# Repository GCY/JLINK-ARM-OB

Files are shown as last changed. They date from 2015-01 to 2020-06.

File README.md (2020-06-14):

# JLINK-ARM-OB
This is JLink-OB ARM ICE tool, [STM32F103 Jan 7 2019 firmware](https://github.com/GCY/JLINK-ARM-OB/blob/master/J-Link%20OB-STM32F103%20V1%20compiled%20Jan%20%207%202019/JLink-OB%20STM32F103%20JLinkARM.dll%20v6.44f%20.bin) extract from v6.44 JLinkARM.dll.

This version([STM32F103 Jan 7 2019](https://github.com/GCY/JLINK-ARM-OB/blob/master/J-Link%20OB-STM32F103%20V1%20compiled%20Jan%20%207%202019/JLink-OB%20STM32F103%20JLinkARM.dll%20v6.44f%20.bin) ) failed to upgrade the firmware of the JLink-OB with JLinkConfig.

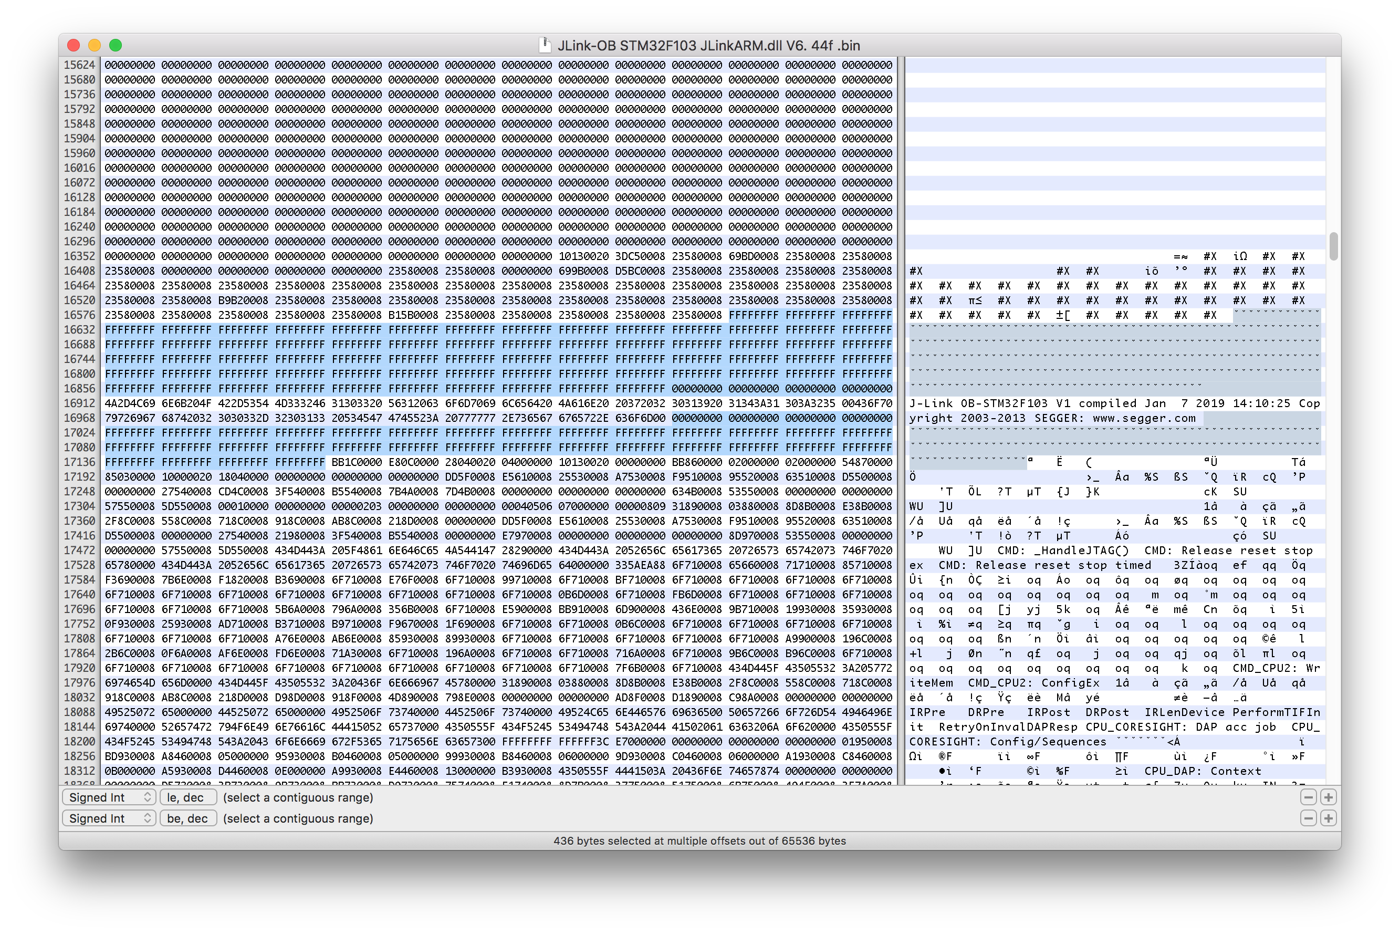
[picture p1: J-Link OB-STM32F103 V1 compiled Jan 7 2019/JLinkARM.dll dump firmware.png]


## Use
 - 1.burning [STM32F103 Jan 7 2019 firmware](https://github.com/GCY/JLINK-ARM-OB/blob/master/J-Link%20OB-STM32F103%20V1%20compiled%20Jan%20%207%202019/JLink-OB%20STM32F103%20JLinkARM.dll%20v6.44f%20.bin) to DIY JLink-OB.
 - 2.Connect targer(For example the following picture is my [STM32F405 Digital Stethoscope project](https://github.com/GCY/Digital-Stethoscope-for-Heart-and-Lung-sounds))
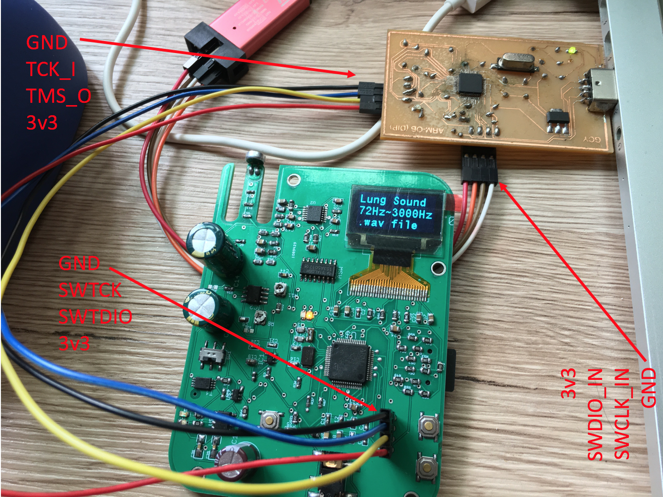
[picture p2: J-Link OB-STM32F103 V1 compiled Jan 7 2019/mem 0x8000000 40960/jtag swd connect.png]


 - 1.Run JLinkExe.
 - 2.J-Link > connect.
 - 3.Select device.     # the example is STM32F405
 - 4.Device > S.        # for SWD Port
 - 5.Speed = 4000kHz
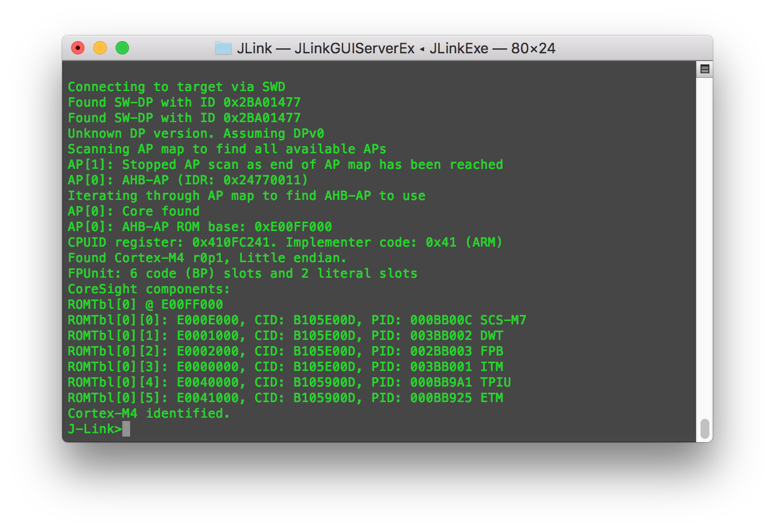
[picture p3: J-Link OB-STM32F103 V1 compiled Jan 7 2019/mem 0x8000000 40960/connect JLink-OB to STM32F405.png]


 - 1.J-Link > mem 0x8000000 40960
 - 2.Test dump target flash.
 - 3.You DIY JLink-OB done.
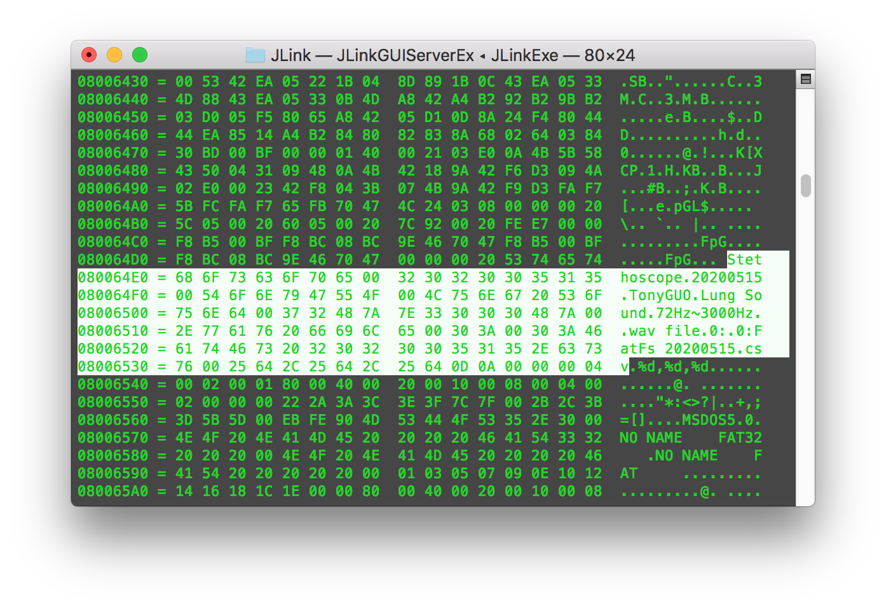
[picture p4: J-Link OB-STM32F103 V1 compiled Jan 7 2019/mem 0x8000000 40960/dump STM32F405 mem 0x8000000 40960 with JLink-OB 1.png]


## Reference
 - [DIY JLink-OB-072 (JLink + COM)](http://akb77.com/g/stm32/jlink-ob/)
 - [JLink hack reference (cht)](https://www.amobbs.com/thread-5653964-1-1.html)
 - [J-Link Commander](https://wiki.segger.com/J-Link_Commander#savebin)
 - [Firmware extract from JLinkARM.dll (cht)](https://blog.csdn.net/qq_39663845/article/details/81086499)

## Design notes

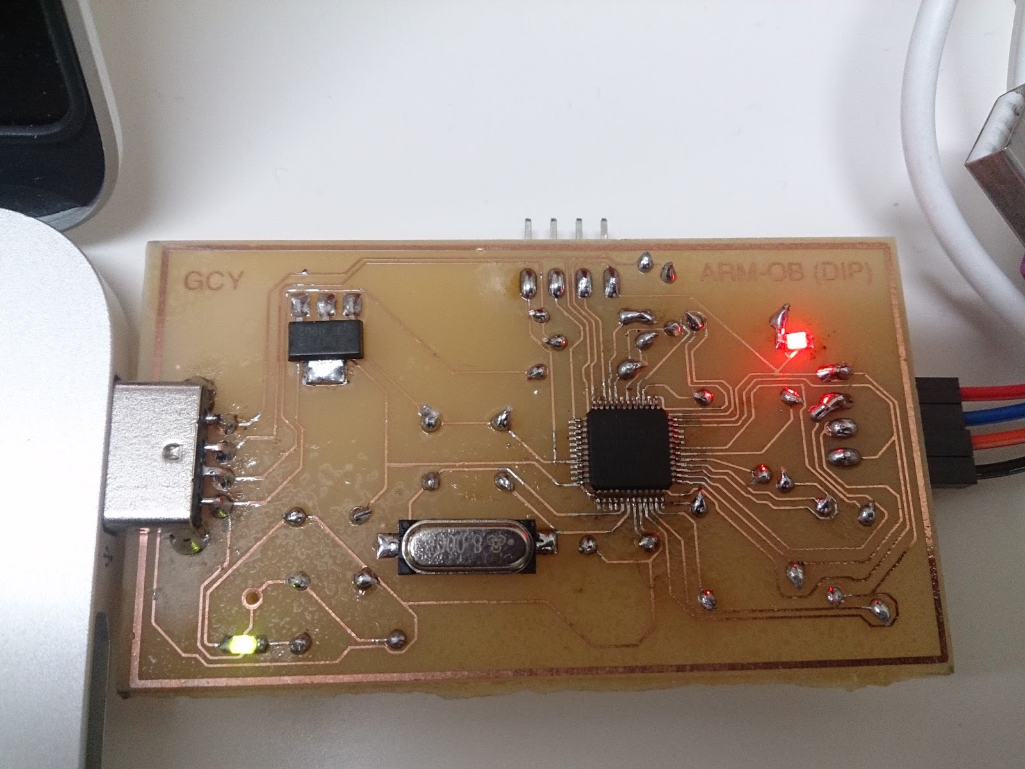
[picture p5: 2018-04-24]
2012 version/hw example.JPG

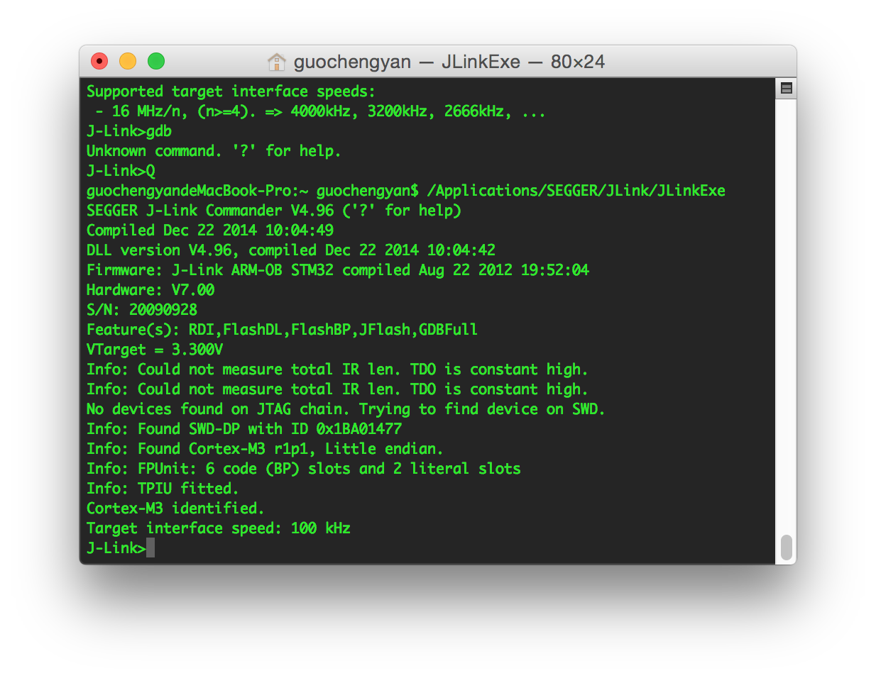
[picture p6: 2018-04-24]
2012 version/J-Link Commander.png

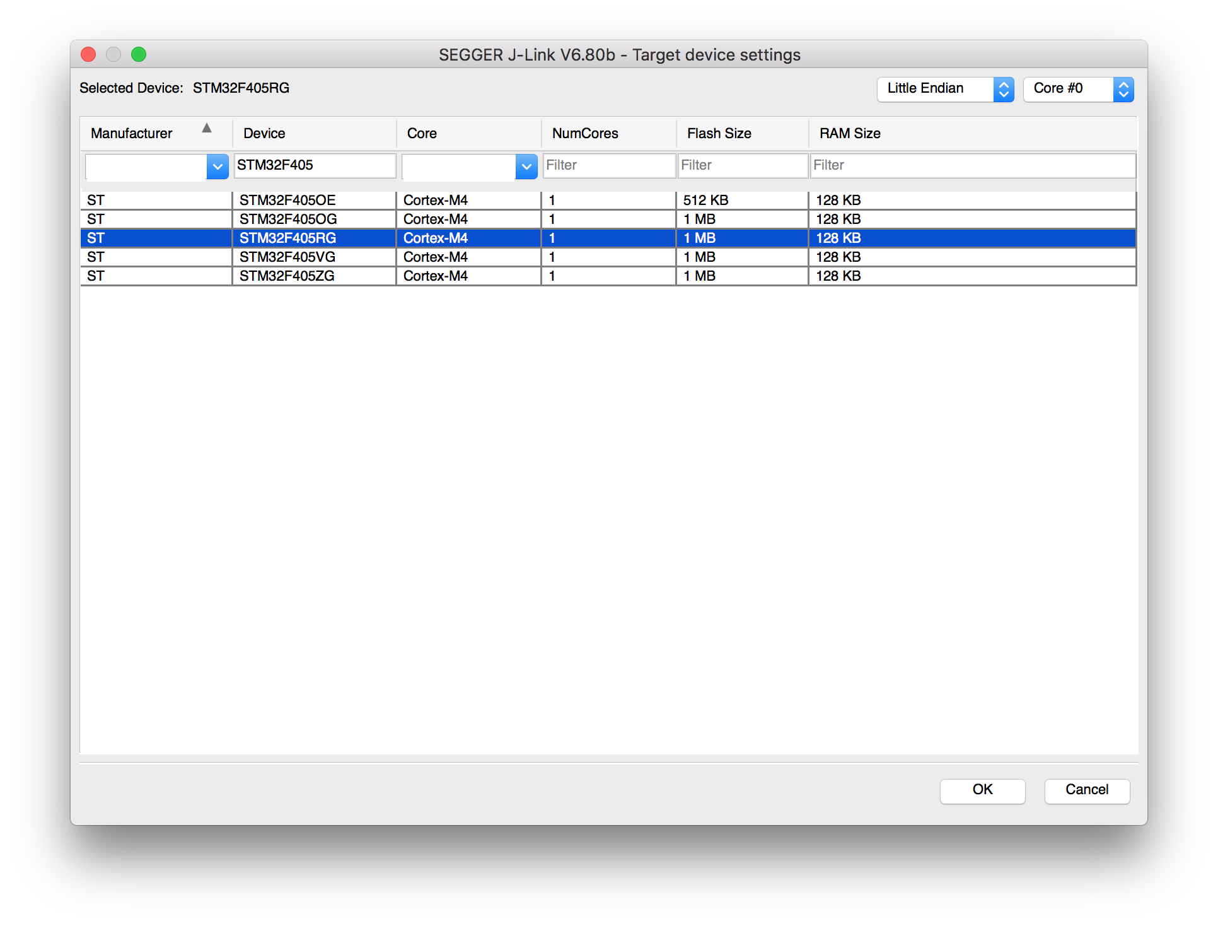
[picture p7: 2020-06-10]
J-Link OB-STM32F103 V1 compiled Jan 7 2019/mem 0x8000000 40960/STM32F405 device.png

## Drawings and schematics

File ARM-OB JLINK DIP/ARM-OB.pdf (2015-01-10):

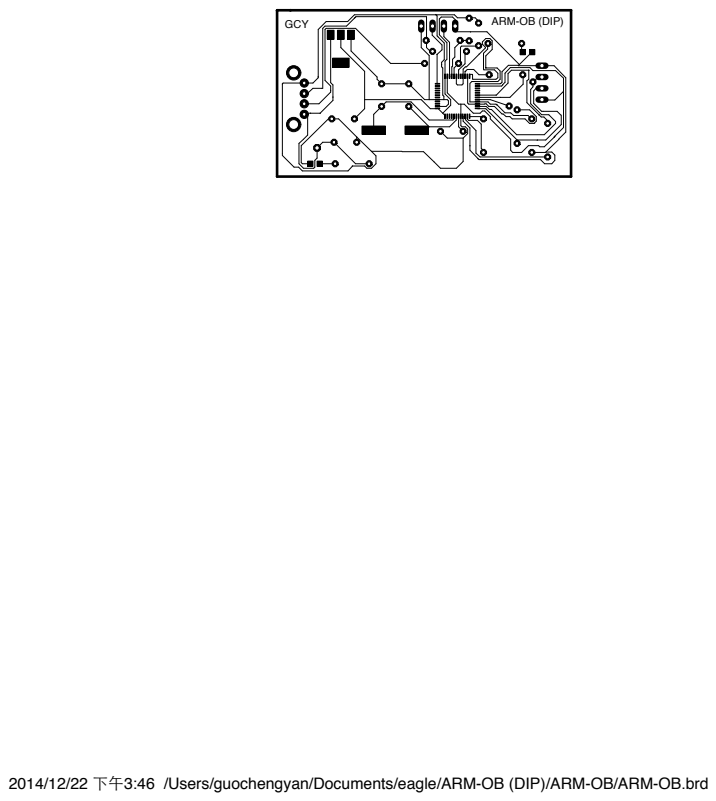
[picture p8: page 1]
GCY; ARM-OB (DIP)

2014/12/22 下午3:46 /Users/guochengyan/Documents/eagle/ARM-OB (DIP)/ARM-OB/ARM-OB.brd

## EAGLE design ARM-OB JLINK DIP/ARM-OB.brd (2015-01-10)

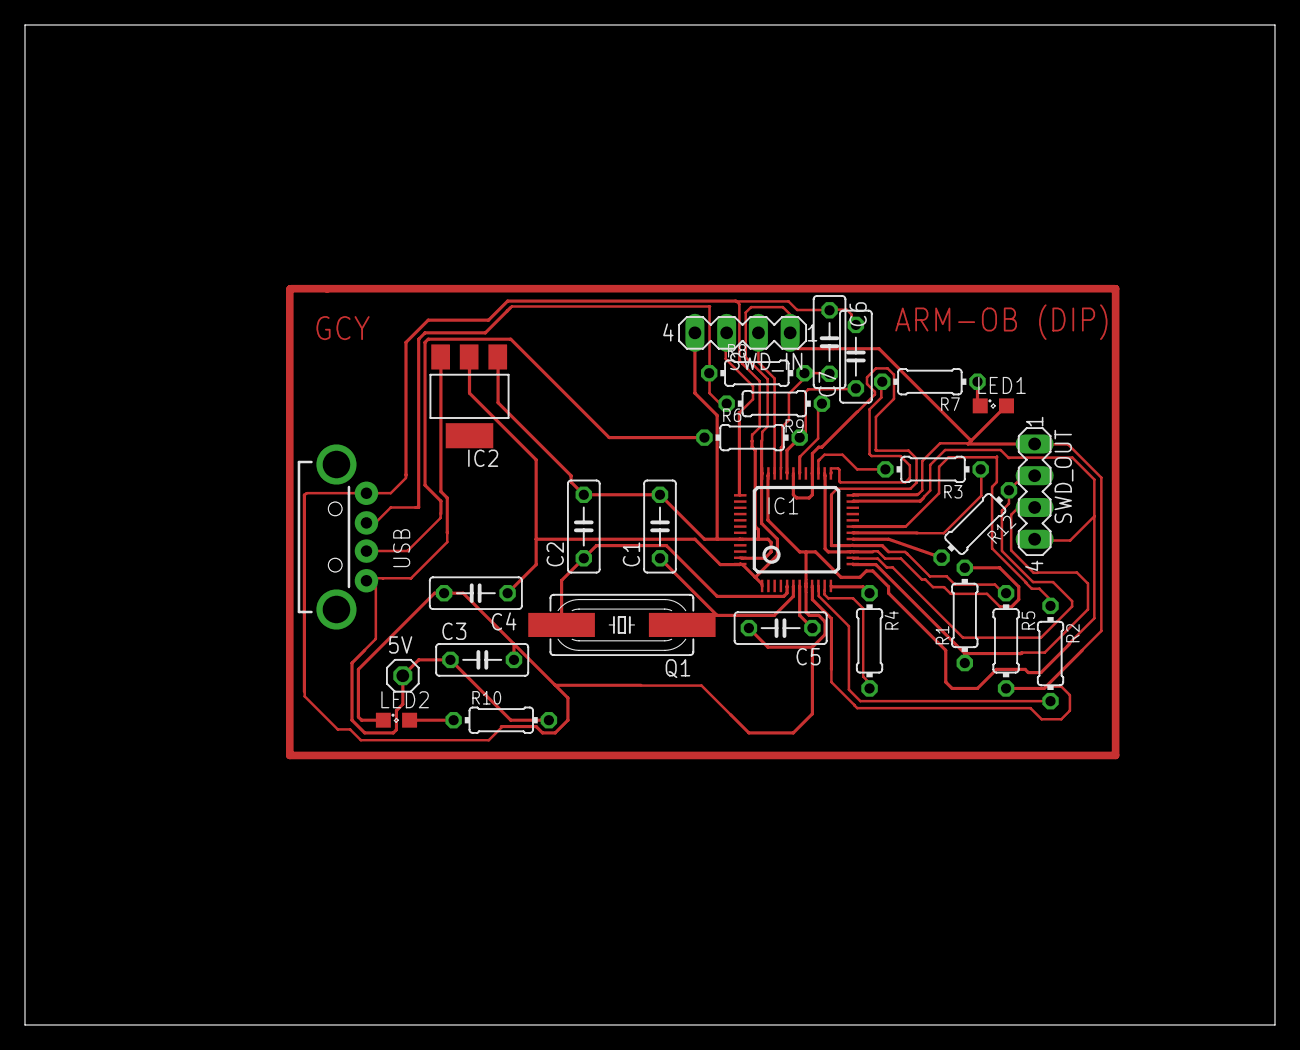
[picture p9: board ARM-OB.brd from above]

Board: 2 copper layers, 100.0 x 80.0 mm, 28 parts (0 on the bottom side), 21 nets.

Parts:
5V: 1X01
C1, C2, C6, C7: 22pF; C050-025X075
C3, C4, C5: 0.1uF; C050-025X075
FRAME1: FRAME-LETTER; CREATIVE_COMMONS
IC1: STM32F10XCXT6; TQFP48
IC2: REG1117; SOT223
LED1, LED2: SML0805
Q1: 8MHz; HC49UP
R1, R2, R3, R4, R12: 100; 0204/7
R5: 10k; 0204/7
R6, R8: 68; 0204/7
R7, R10: 1k; 0204/7
R9: 1.5k; 0204/7
SWD_IN: MA04-1
SWD_OUT: MA04-1
USB: USB-A-H

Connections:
D-: IC1.32, R6.2
unnamed: C5.1, IC1.7
unnamed: C2.1, IC1.5, Q1.2
unnamed: C1.1, IC1.6, Q1.1
unnamed: LED2.A, R10.1
unnamed: LED1.C, R7.1
S$14: IC1.14, R12.1
S$30: C1.2, C2.2, IC1.44, IC1.47, IC2.1, SWD_IN.4
S$32: C5.2, IC1.8, IC1.35
S$34: LED1.A, SWD_OUT.1
S$38: IC1.28, IC1.31
S$47: C3.2, C4.2, LED2.C
SWDIO_IN: IC1.34, SWD_IN.2
TCK_I: IC1.13, R1.1
TCK_O: IC1.15, IC1.26
TDI_O: IC1.27, R3.2
TMS_O: IC1.17, R12.2
TRES_I: IC1.12, R4.1
TRST_O: IC1.10, R2.2
VCC: 5V.1, C3.1, R10.2
VDD: C4.1, IC1.1, IC1.36, IC1.48, IC2.2

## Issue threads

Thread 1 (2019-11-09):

Does this support the Reset pin to the target ?

rogerclarkmelbourne, 2019-11-09:
I don't think its  possible t use this on some MCU's because the target needs to be reset while some SWD commands are sent, in order to remove the read protection and erase the IC e.g. most NXP processors need this ?

GCY, 2019-11-10:
Yes, it's only TMS and TCK(3-wire mode), if you need to reset your target device,  connect PA1 and reset pin with wire jump.

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

Reference J-LINK full function SWD and JTAG
PA0 Activity LED
PA1 RESET
PA2 SWCLK(TCK)
PA3 SWO(TDO)
PA4 SWDIO(TMS)
PA9 RX
PA10 TX

rogerclarkmelbourne, 2019-11-10:
Excellent.

Thanks.

kaehless, 2020-06-06:
Going by your eagle schematic

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

@GCY should this be ?

PA2 nRESET
PA3 SWCLK
PA4 SWDIO

Note: using PA3 (CLK) & PA4 (DIO) seems to work.

You seem to be using PB12 for activity light

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

kaehless, 2020-06-06:
Oh nvm, I saw the JLINK OB datasheet. I misread the schematic, thanks

Closed 2019-11-10.

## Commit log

2015-01-10 DIP Version
    [ARM-OB.brd, ARM-OB.sch]
2020-06-10 J-Link OB-STM32F103 V1 compiled Jan 7 2019

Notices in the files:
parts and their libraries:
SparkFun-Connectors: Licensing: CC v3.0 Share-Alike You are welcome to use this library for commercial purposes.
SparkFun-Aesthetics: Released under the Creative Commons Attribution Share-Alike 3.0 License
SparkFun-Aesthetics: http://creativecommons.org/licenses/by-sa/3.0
